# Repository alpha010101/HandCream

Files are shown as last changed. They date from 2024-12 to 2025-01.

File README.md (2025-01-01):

###
RP2040を使ったマイコン基板で、基本的にはRaspberry-pi pico互換。

24V系の機器を制御するのが目的で、そのために東芝のDMOS-SINKドライバTBD62064が載っている。本当ならカプラで分離するのが適当なのだろうが、こんなもんで問題なく動いてる

電源は24VをXHコネクタから入れる想定。それをTIのUA78M05で5V/0.5Aに落とし、それを更にMicrochipのMIC5504で3.3V/0.3Aに落としている。3.3VはMCU用、5VはLEDと冷却ファンの駆動用

SchematicsとPCB-LayoutはAutodesk-Eagle無償版を使用し、elecrowで製造することを想定したガーバーを作成している

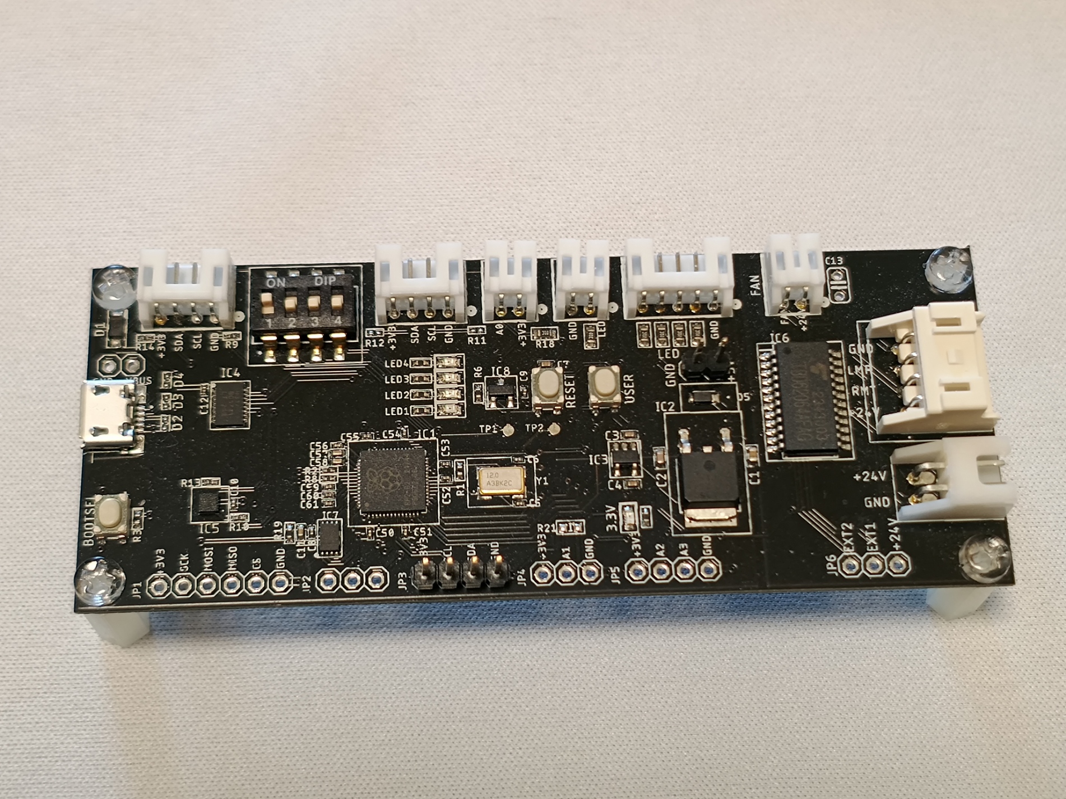
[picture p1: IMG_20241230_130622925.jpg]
HandCream


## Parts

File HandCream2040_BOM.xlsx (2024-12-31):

Part# | Device | Qty | Manufacturer | Package | Value | Description | Source | MOUSER_PART_NUMBER | MOUSER_PRICE-STOCK
C1 | CGA3E3X5R1H334K080AB | 1 | TDK | CAPC1608X90N | 0.33uF | Multilayer Ceramic Capacitor, 50V, 10%, X5R, 1608 (0603), Or equivalent | mouser or Elecrow | 810-CGA3E3X5R1H334KB | https://www.mouser.co.uk/ProductDetail/TDK/CGA3E3X5R1H334K080AB?qs=xLDY6iXSiQYI%252BjKItkDhww%3D%3D
C2 | C1608X5R1H104K080AA | 1 | TDK | CAPC1608X80N | 0.1uF | Multilayer Ceramic Capacitor, 50V, 10%, X5R, 1608 (0603), Or equivalent | mouser or Elecrow | 810-C1608X5R1H104K | https://www.mouser.co.uk/ProductDetail/TDK/C1608X5R1H104K080AA?qs=NRhsANhppD%2Fot2mSfg3j9A%3D%3D
C3,C4,C7 | GRM155R61E105KE11J | 3 | Murata Electronics | CAPC1005X55N | 1uF | Multilayer Ceramic Capacitor, 25V, 10%, X5R, 1005 (0402), Or equivalent | mouser or Elecrow | 81-GRM155R61E105KE1J | https://www.mouser.co.uk/ProductDetail/Murata-Electronics/GRM155R61E105KE11J?qs=QzBtWTOodeVRe4OtPvgZ4A%3D%3D
C5,C6 | GRM0335C1E150FA01D | 2 | Murata Electronics | CAPC0603X33N | 15pF | Multilayer Ceramic Capacitor, 25V, 1%, C0G, 0603 (0201), Or equivalent | mouser or Elecrow | 81-GRM0335C1E150FA1D | https://www.mouser.co.uk/ProductDetail/Murata-Electronics/GRM0335C1E150FA01D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
C8,C9,C10,C12,C50,C51,C52, C53,C54,C55,C56,C59,C60,C61 | GRM033R60J104KE19D | 14 | Murata Electronics | CAPC0603X33N | 0.1uF | Multilayer Ceramic Capacitor, 6.3V, 10%, X5R, 0603 (0201), Or equivalent | mouser or Elecrow | 81-GRM033R60J104KE19 | https://www.mouser.co.uk/ProductDetail/Murata-Electronics/GRM033R60J104KE19D?qs=GaSm9ipITa4x559m0GMeJg%3D%3D
C11,C57,C58 | GRM155R61A225KE01J | 3 | Murata Electronics | CAPC1005X55N | 2.2uF | Multilayer Ceramic Capacitor, 10V, 10%, X5R, 1005 (0402), Or equivalent | mouser or Elecrow | 81-GRM155R61A225K01J | https://www.mouser.co.uk/ProductDetail/Murata-Electronics/GRM155R61A225KE01J?qs=T3oQrply3y82IrfvEpRQug%3D%3D
C13 |  | 0 |  |  |  | No need to assemble
D1 | MBR120VLSFT1G | 1 | onsemi | SODFL3616X98N |  | Diode Schottky 20V, 1A, SOD-123FL | mouser or Elecrow | 863-MBR120VLSFT1G | https://www.mouser.co.uk/ProductDetail/onsemi/MBR120VLSFT1G?qs=3JMERSakebpX%252BkItPpFCkg%3D%3D
D2,D3,D4 | DF2S6.8FS,L3M | 0 | Toshiba | SODFL1006X45N |  | No need to assemble
D5 | VS-1EQH01HM3_H | 1 | Vishay | VS1EQH01HM3H |  | Rectifiers 100V 1A Fred Pt MicroSMP (DO-219AD) | mouser or Elecrow | 78-VS-1EQH01HM3/H | https://www.mouser.co.uk/ProductDetail/Vishay-Semiconductors/VS-1EQH01HM3-H?qs=BJlw7L4Cy78xxlCx4HTbcA%3D%3D
IC1 | SC0914(13) / RP2040 | 1 | RASPBERRY-PI | SC091413 |  | ARM Cortex-M0+ - Microcontroller IC 32-Bit Dual-Core 133MHz External Program Memory 56-QFN (7x7) | mouser or Elecrow | 358-SC091413 | https://www.mouser.co.uk/ProductDetail/Raspberry-Pi/SC091413?qs=T%252BzbugeAwjhr%252BUbBr3TJcw%3D%3D
IC2 | UA78M05CKVURG3 | 1 | Texas Instruments | TPS7A6533QKVURQ1 |  | Linear Voltage Regulators, 500mA, 5V-output, max25V, | mouser or Elecrow | 595-UA78M05CKVURG3 | https://www.mouser.co.uk/ProductDetail/Texas-Instruments/UA78M05CKVURG3?qs=0O%2FZFlpUpJXWzCHdAbvEiw%3D%3D
IC3 | MIC5504-3.3YM5-TR | 1 | Microchip | SOT95P280X145-5N |  | LDO Voltage Regulators, 300mA, 3.3V-output, max5.5V, SOT-23-5 | mouser or Elecrow | 998-MIC5504-3.3YM5TR | https://www.mouser.co.uk/ProductDetail/Microchip-Technology/MIC5504-3.3YM5-TR?qs=U6T8BxXiZAUmVQ5Zs217qQ%3D%3D
IC4 | LTC4317CDHC#PBF | 1 | Analog Devices | SON50P300X500X80-17N |  | Specialized Interface, I2C, SMBus, I2C Bus & SMBus Systems Applications, Servers, Telecom, 2.25 V | mouser or Elecrow | 584-LTC4317CDHC#PBF | https://www.mouser.com/Search/Refine.aspx?Keyword=584-LTC4317CDHC%23PBF
IC5 | MC3479 | 1 | MEMSIC | MC3479 |  | Accelerometers Small Digital 3-axis Accelerometer Sensor | mouser or Elecrow | 498-MC3479 | https://www.mouser.co.uk/ProductDetail/MEMSIC/MC3479?qs=OlC7AqGiEDmYmlaMvA9fTA%3D%3D
IC6 | TBD62064AFAG,EL | 1 | Toshiba | SOP100P800X190-24N |  | Gate Drivers DMOS Transistor Array 50V 1500mA | mouser or Elecrow | 757-TBD62064AFAGEHZ | https://www.mouser.co.uk/ProductDetail/Toshiba/TBD62064AFAGEL?qs=%252BEew9%252B0nqrBmaXxMy0ki7g%3D%3D
IC7 | W25Q16JVUXIQ_TR | 1 | Winbond | SON50P300X200X60-9N |  | NOR Flash spiFlash, 3V, 16M-bit, 4Kb Uniform Sector, DTR | mouser or Elecrow | 454-W25Q16JVUXIQTR | https://www.mouser.co.uk/ProductDetail/Winbond/W25Q16JVUXIQ-TR?qs=qSfuJ%252Bfl%2Fd7SDdIHLGOd1g%3D%3D
IC8 | MCP111T-315E_TT | 1 | Microchip | SOT96P237X112-3N |  | Voltage Supervisor 3.003 3.157 V, 3-Pin SOT-23B | mouser or Elecrow | 579-MCP111T-315E/TT | https://www.mouser.co.uk/ProductDetail/Microchip-Technology/MCP111T-315E-TT/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
J1 | S04B-XASS-1N-BN_LF__SN_ | 0 | JST | S04BXASS1NBNLFSN |  | No need to assemble
J2 | S2B-XH-A(LF)(SN) | 0 | JST | JST_S2B-XH-A(LF)(SN) |  | No need to assemble
J3,J4 | S4B-PH-K-S(LF)(SN) | 0 | JST | CONN_S4B-PH-K-S_JST |  | No need to assemble
J5,J6,J8 | S2B-PH-K-S(LF)(SN) | 0 | JST | CONN_S2B-PH-K-S_JST |  | No need to assemble
J7 | S5B-PH-K-S_(LF)(SN) | 0 | JST | CONN_S5B-PH-K-S_JST |  | No need to assemble
J9 | 10103594-0001LF | 1 | Amphenol ICC | AMPHENOL_10103594-0001LF |  | USB - micro B USB 2.0 Receptacle Connector 5 Position Surface Mount, Right Angle; Through Hole | mouser or Elecrow
LED1,LED2,LED3,LED4,LED5 | 150060VS75000 | 5 | Wurth Elektronik | LEDC1608X80N |  | Green LED, 2V/20mA, 1608 (0603) | mouser or Elecrow | 710-150060VS75000 | https://www.mouser.co.uk/ProductDetail/Wurth-Elektronik/150060VS75000?qs=LlUlMxKIyB1Q1Bi5mQ%2FKLw%3D%3D
R1,R3 | CRCW04021K00FKEDC | 2 | Vishay | RESC1005X35N | 1KΩ | Thick Film Resistor, 1005(0402), 1K, 1%, 0.063W(1/16W), Or equivalent | mouser or Elecrow | 71-CRCW04021K00FKEDC | https://www.mouser.co.uk/ProductDetail/Vishay-Dale/CRCW04021K00FKEDC?qs=E3Y5ESvWgWMj5mY%252BhDIyqg%3D%3D
R2,R8 | CRCW020127R0FNED | 2 | Vishay | RESC0603X28N | 27Ω | Thick Film Resistor, 0603(0201), 27, 1%, 0.05W(1/20W), Or equivalent | mouser or Elecrow | 71-CRCW020127R0FNED | https://www.mouser.co.uk/ProductDetail/Vishay-Dale/CRCW020127R0FNED?qs=3bSaU8eFeoG6a73XMZKF3w%3D%3D
R4,R7,R15,R16, R17,R18 | CRCW060310K0FKECC | 6 | Vishay | RESC1608X55N | 10KΩ | Thick Film Resistor, 1608(0603), 10K, 1%, 0.1W(1/10W), Or equivalent | mouser or Elecrow | 71-CRCW060310K0FKECC | https://www.mouser.co.uk/ProductDetail/Vishay-Dale/CRCW060310K0FKECC?qs=wd5RIQLrsJjYJGKL%252BLOtbQ%3D%3D
R21 | CRCW060310K0FKECC | 0 | Vishay | RESC1608X55N | 10KΩ | No need to assemble (pulldown)
R6,R19 | CRCW040210K0FKEDC | 2 | Vishay | RESC1005X35N | 10KΩ | Thick Film Resistor, 1005(0402), 10K, 1%, 0.063W(1/16W), Or equivalent | mouser or Elecrow | 71-CRCW040210K0FKEDC | https://www.mouser.co.uk/ProductDetail/Vishay-Dale/CRCW040210K0FKEDC?qs=E3Y5ESvWgWPiNLcGzwCGPg%3D%3D
R9,R10,R13,R14 | CRCW02014K70FNED | 4 | Vishay | RESC0603X28N | 4.7KΩ | Thick Film Resistor, 0603(0201), 4.7K, 1%, 0.05W(1/20W), Or equivalent | mouser or Elecrow | 71-CRCW02014K70FNED | https://www.mouser.co.uk/ProductDetail/Vishay-Dale/CRCW02014K70FNED?qs=9Aka%2FNDvCXDQ%2Fr1WGNjziQ%3D%3D
R11,R12 | CRCW02014K70FNED | 0 | Vishay | RESC0603X28N | 4.7KΩ | No need to assemble (I2C pullup)
R5,R22,R23,R24,R25 | CRCW0402620RFKED | 5 | Vishay | RESC1005X40N | 620Ω | Thick Film Resistor 1005(0402), 620, 1%, 0.063W(1/16W), Or equivalent | mouser or Elecrow | 71-CRCW0402-620-E3 | https://www.mouser.com/Search/Refine.aspx?Keyword=71-CRCW0402-620-E3
S1,S2,S3 | SKRPACE010 | 3 | ALPS Electric | SMT(4.2X3.2) |  | Tactile Switches 4.2x3.2x2.5mm 260gf | mouser or Elecrow | 688-SKRPACE010 | https://www.mouser.co.uk/ProductDetail/Alps-Alpine/SKRPACE010?qs=dHDuPHwQO79W8iY66hDbLQ%3D%3D
S4 | 219-4MST | 1 | CTS | 2194MST |  | DIP Switches / SIP Switches | mouser or Elecrow | 774-2194MST | https://www.mouser.co.uk/ProductDetail/CTS-Electronic-Components/219-4MST?qs=qNzHFtQhdJ8xGV2Z9mul9A%3D%3D
Y1 | ABM3BAIG-12.000MHZ-12-4-T | 1 | ABRACON | ABM3BAIG |  | 12 MHz +/-30ppm Crystal 12pF 70 Ohms 4-SMD, No Lead | mouser or Elecrow | 815-ABM3BAIG1212-4T | https://www.mouser.co.uk/ProductDetail/ABRACON/ABM3BAIG-12000MHz-12-4-T?qs=0lSvoLzn4L9fUl2r3xsu2A%3D%3D

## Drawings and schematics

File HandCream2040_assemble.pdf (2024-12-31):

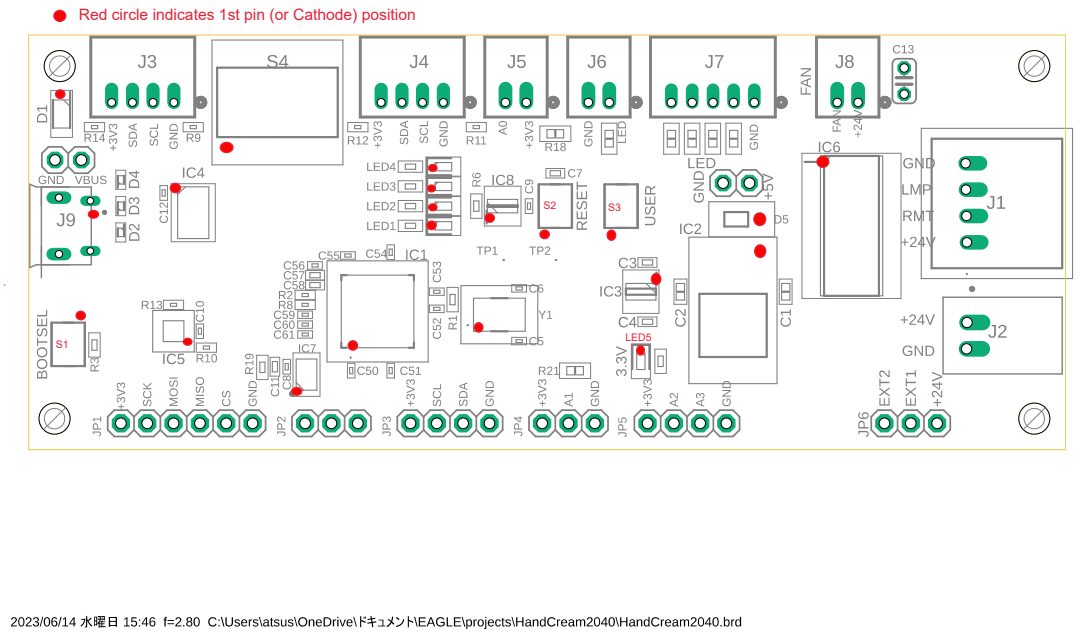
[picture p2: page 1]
LED5

Red circle indicates 1st pin (or Cathode) position

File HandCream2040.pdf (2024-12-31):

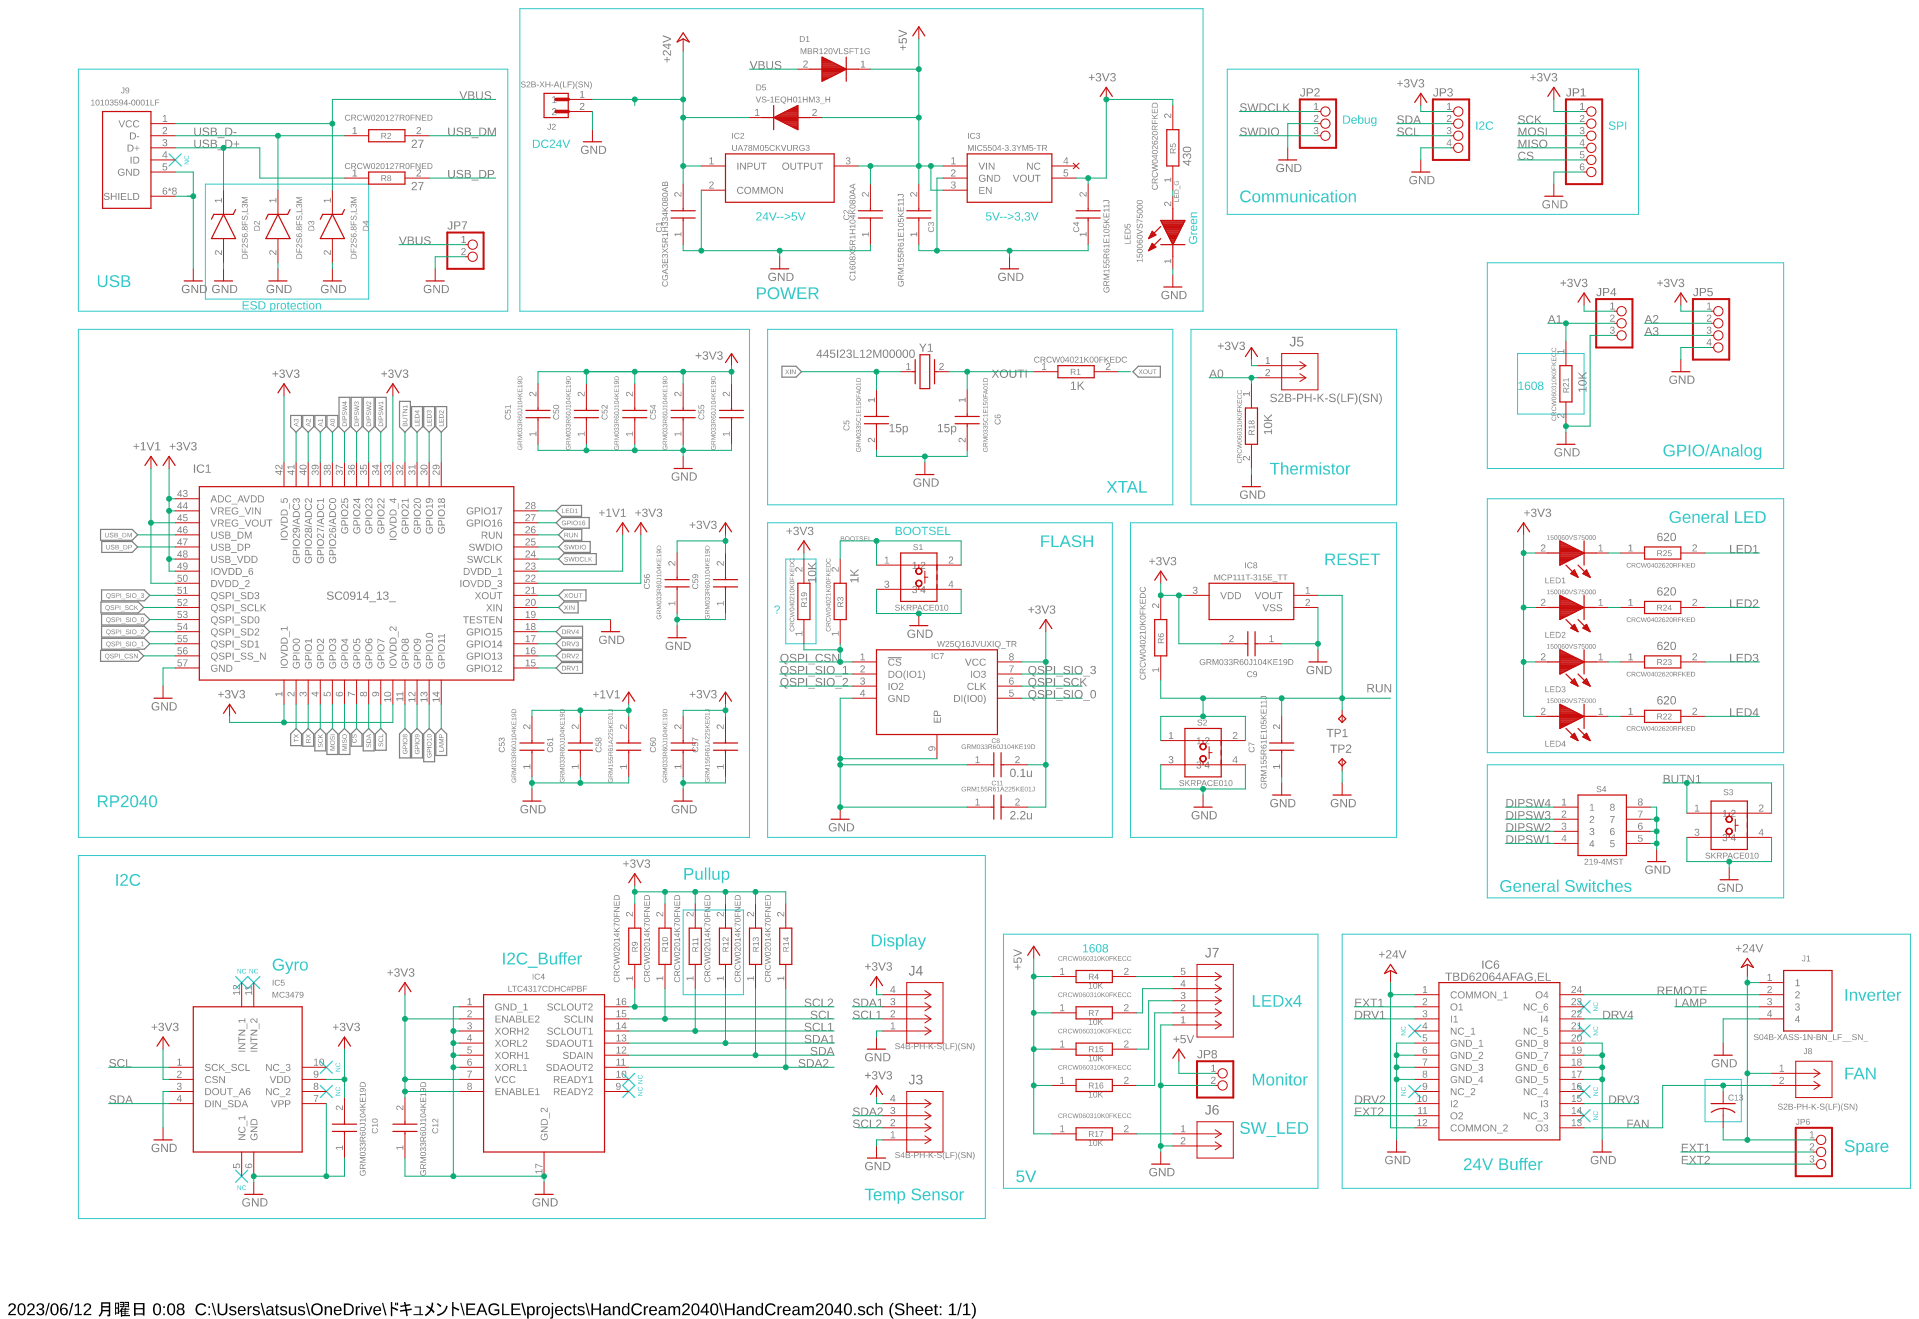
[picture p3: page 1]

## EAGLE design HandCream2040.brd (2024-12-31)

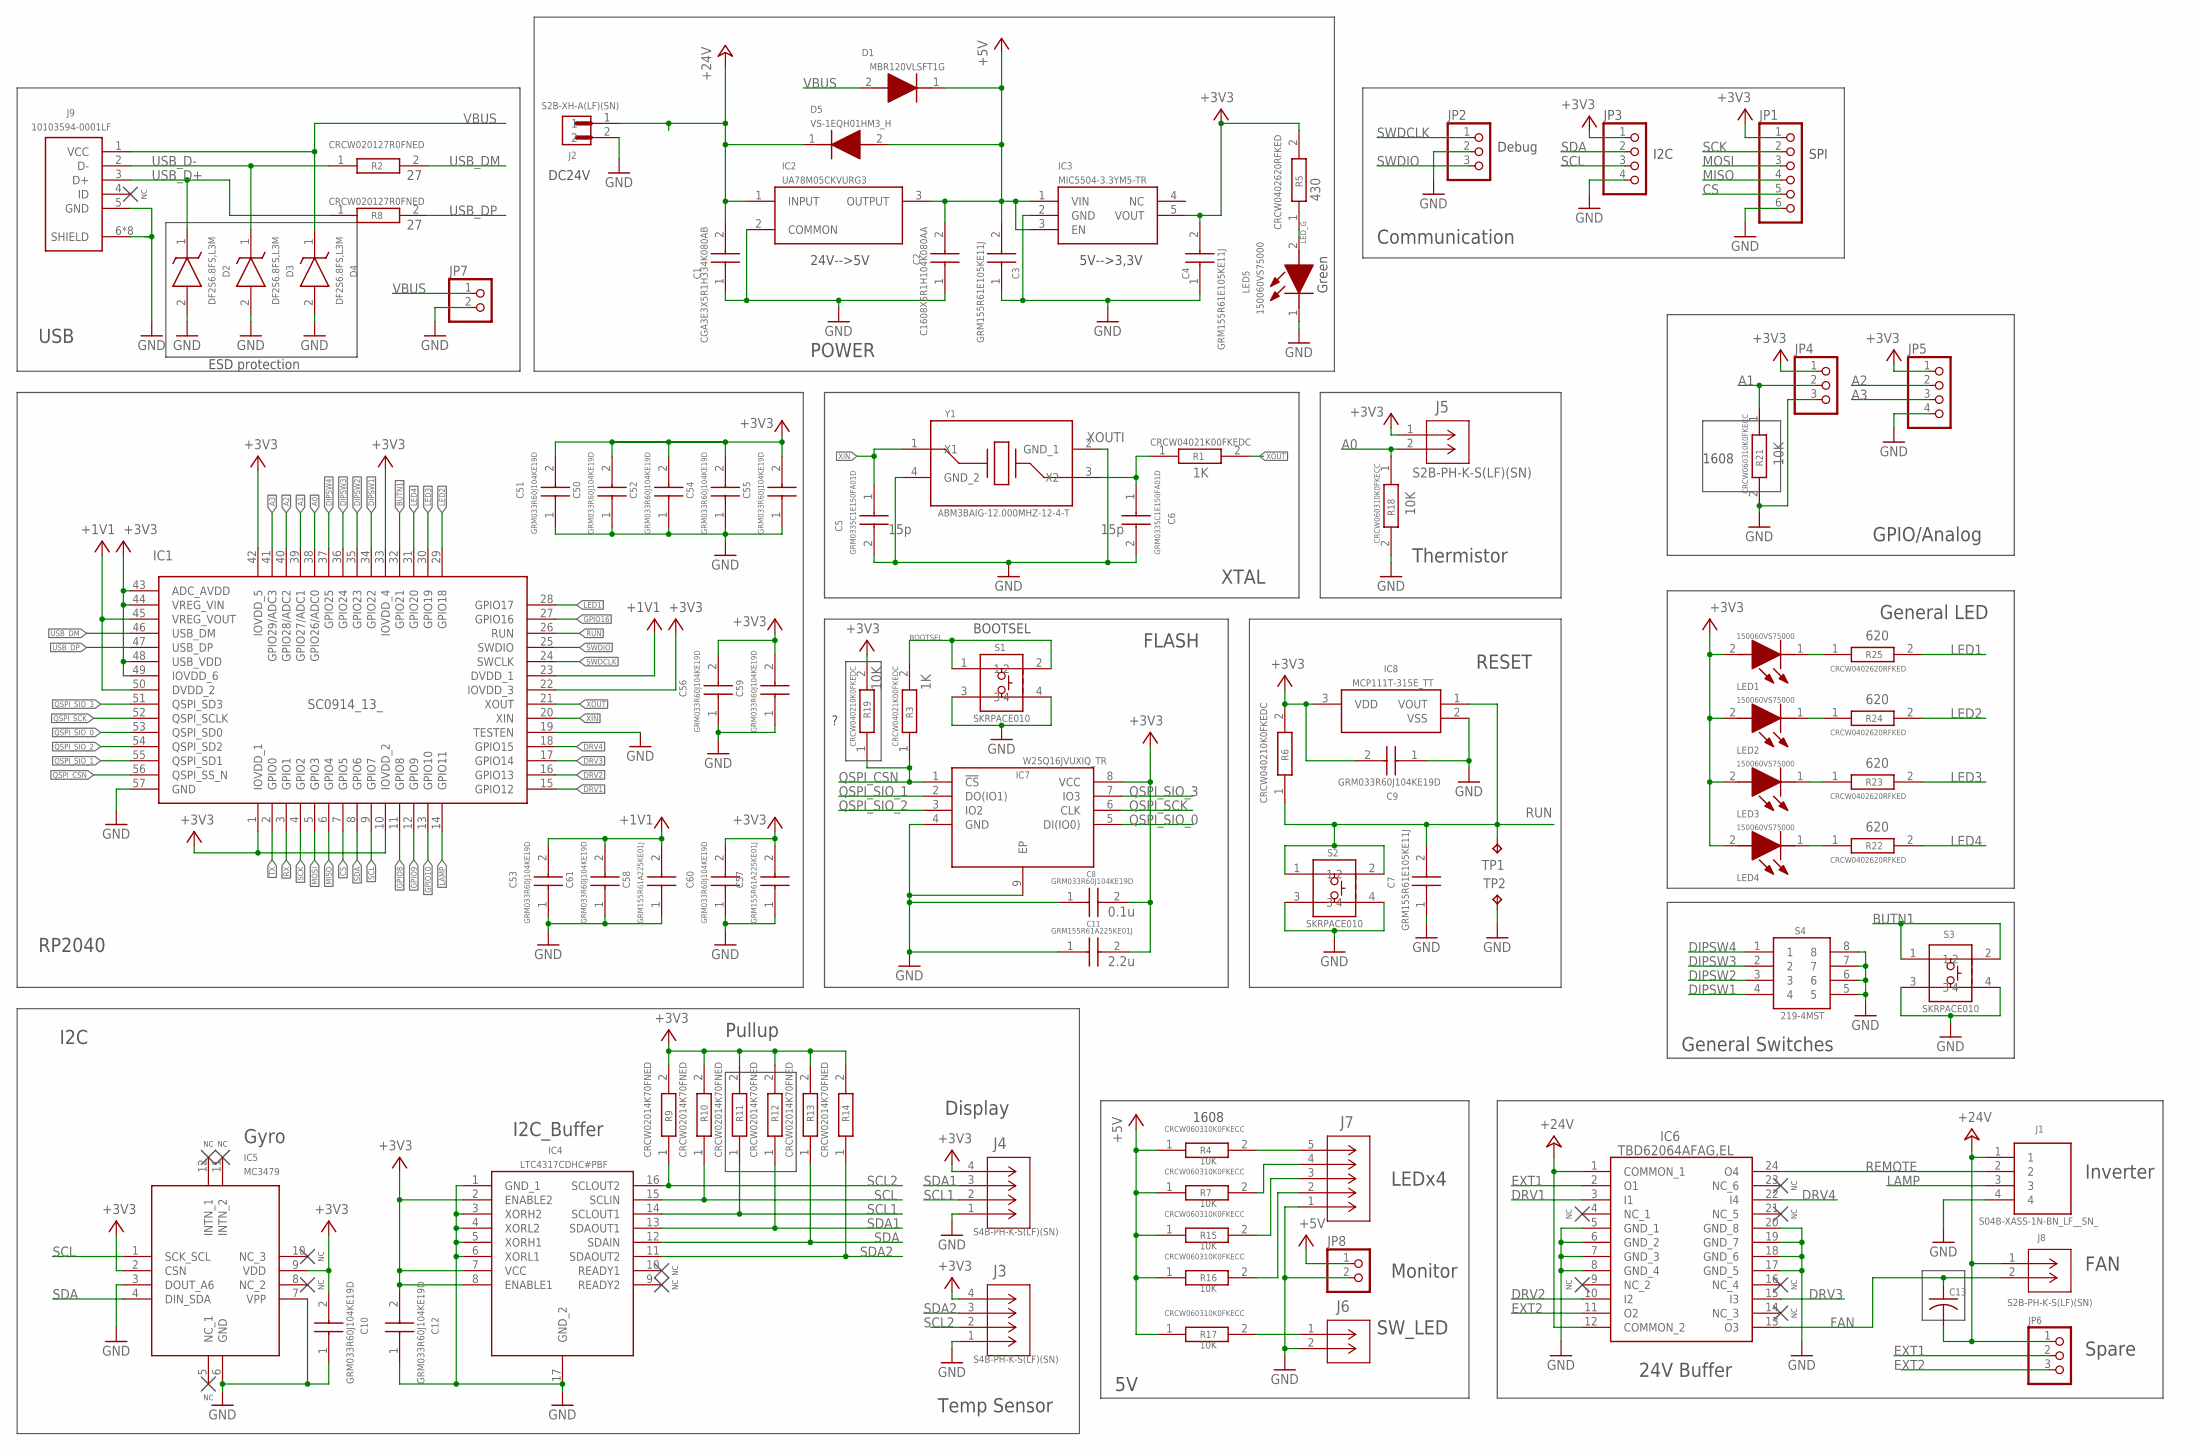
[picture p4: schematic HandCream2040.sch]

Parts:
C1: CGA3E3X5R1H334K080AB; CAPC1608X90N
C2: C1608X5R1H104K080AA; CAPC1608X80N
C3, C4, C7: GRM155R61E105KE11J; CAPC1005X55N
C5, C6: GRM0335C1E150FA01D; CAPC0603X33N
C8, C9, C10, C12, C50, C51, C52, C53, C54, C55, C56, C59, C60, C61: GRM033R60J104KE19D; CAPC0603X33N
C11, C57, C58: GRM155R61A225KE01J; CAPC1005X55N
C13: C-US025-024X044; C025-024X044
D1: MBR120VLSFT1G; SODFL3616X98N
D2, D3, D4: DF2S6.8FS,L3M; SODFL1006X45N
D5: VS-1EQH01HM3_H; VS1EQH01HM3H
IC1: SC0914_13_; SC091413
IC2: UA78M05CKVURG3; TPS7A6533QKVURQ1
IC3: MIC5504-3.3YM5-TR; SOT95P280X145-5N
IC4: LTC4317CDHC#PBF; SON50P300X500X80-17N
IC5: MC3479
IC6: TBD62064AFAG,EL; SOP100P800X190-24N
IC7: W25Q16JVUXIQ_TR; SON50P300X200X60-9N
IC8: MCP111T-315E_TT; SOT96P237X112-3N
J1: S04B-XASS-1N-BN_LF__SN_; S04BXASS1NBNLFSN
J2: S2B-XH-A(LF)(SN); JST_S2B-XH-A(LF)(SN)
J3, J4: S4B-PH-K-S(LF)(SN); CONN_S4B-PH-K-S_JST
J5, J6, J8: S2B-PH-K-S(LF)(SN); CONN_S2B-PH-K-S_JST
J7: S5B-PH-K-S_(LF)(SN); CONN_S5B-PH-K-S_JST
J9: 10103594-0001LF; AMPHENOL_10103594-0001LF
JP1: PINHD-1X6; 1X06
JP2, JP4, JP6: PINHD-1X3; 1X03
JP3, JP5: PINHD-1X4; 1X04
JP7, JP8: PINHD-1X2; 1X02
LED1, LED2, LED3, LED4, LED5: 150060VS75000; LEDC1608X80N
R1, R3: CRCW04021K00FKEDC; RESC1005X35N
R2, R8: CRCW020127R0FNED; RESC0603X28N
R4, R7, R15, R16, R17, R18, R21: CRCW060310K0FKECC; RESC1608X55N
R5, R22, R23, R24, R25: CRCW0402620RFKED; RESC1005X40N
R6, R19: CRCW040210K0FKEDC; RESC1005X35N
R9, R10, R11, R12, R13, R14: CRCW02014K70FNED; RESC0603X28N
S1, S2, S3: SKRPACE010; SMT(4.2X3.2)
S4: 219-4MST; 2194MST
TP1, TP2: TPB1,27; B1,27
Y1: ABM3BAIG-12.000MHZ-12-4-T; ABM3BAIG

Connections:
+1V1: C53.2, C58.2, C61.2, IC1.23 (DVDD_1), IC1.45 (VREG_VOUT), IC1.50 (DVDD_2)
+3V3: C4.2, C8.2, C9.2, C10.2, C11.2, C12.2, C50.2, C51.2, C52.2, C54.2, C55.2, C56.2, C57.2, C59.2, C60.2, IC1.1 (IOVDD_1), IC1.10 (IOVDD_2), IC1.22 (IOVDD_3), IC1.33 (IOVDD_4), IC1.42 (IOVDD_5), IC1.43 (ADC_AVDD), IC1.44 (VREG_VIN), IC1.48 (USB_VDD), IC1.49 (IOVDD_6), IC3.5 (VOUT), IC4.2 (ENABLE2), IC4.7 (VCC), IC4.8 (ENABLE1), IC5.2 (CSN), IC5.9 (VDD), IC7.8 (VCC), IC8.3 (VDD), J3.4, J4.4, J5.1, JP1.1, JP3.1, JP4.1, JP5.1, LED1.2 (A), LED2.2 (A), LED3.2 (A), LED4.2 (A), R5.2, R6.2, R9.2, R10.2, R11.2, R12.2, R13.2, R14.2, R19.2
+5V: C2.2, C3.2, D1.1 (K), D5.2 (A), IC2.3 (OUTPUT), IC3.1 (VIN), IC3.3 (EN), JP8.1, R4.1, R7.1, R15.1, R16.1, R17.1
+24V: C1.2, C13.2, D5.1 (K), IC2.1 (INPUT), IC6.1 (COMMON_1), IC6.12 (COMMON_2), J1.1, J2.1, J8.1, JP6.1
A0: IC1.38 (GPIO26/ADC0), J5.2, R18.1
A1: IC1.39 (GPIO27/ADC1), JP4.2, R21.1
A2: IC1.40 (GPIO28/ADC2), JP5.2
A3: IC1.41 (GPIO29/ADC3), JP5.3
BOOTSEL: R3.2, S1.1, S1.2
BUTN1: IC1.32 (GPIO21), S3.1, S3.2
CS: IC1.7 (GPIO5), JP1.5
DIPSW1: IC1.34 (GPIO22), S4.4
DIPSW2: IC1.35 (GPIO23), S4.3
DIPSW3: IC1.36 (GPIO24), S4.2
DIPSW4: IC1.37 (GPIO25), S4.1
DRV1: IC1.15 (GPIO12), IC6.3 (I1)
DRV2: IC1.16 (GPIO13), IC6.10 (I2)
DRV3: IC1.17 (GPIO14), IC6.15 (I3)
DRV4: IC1.18 (GPIO15), IC6.22 (I4)
EXT1: IC6.2 (O1), JP6.2
EXT2: IC6.11 (O2), JP6.3
FAN: C13.1, IC6.13 (O3), J8.2
GND: C1.1, C2.1, C3.1, C4.1, C5.2, C6.2, C7.1, C8.1, C9.1, C10.1, C11.1, C12.1, C50.1, C51.1, C52.1, C53.1, C54.1, C55.1, C56.1, C57.1, C58.1, C59.1, C60.1, C61.1, D2.2 (A), D3.2 (A), D4.2 (A), IC1.19 (TESTEN), IC1.57 (GND), IC2.2 (COMMON), IC3.2 (GND), IC4.1 (GND_1), IC4.3 (XORH2), IC4.4 (XORL2), IC4.5 (XORH1), IC4.6 (XORL1), IC4.17 (GND_2), IC5.3 (DOUT_A6), IC5.6 (GND), IC5.7 (VPP), IC6.5 (GND_1), IC6.6 (GND_2), IC6.7 (GND_3), IC6.8 (GND_4), IC6.17 (GND_5), IC6.18 (GND_6), IC6.19 (GND_7), IC6.20 (GND_8), IC7.4 (GND), IC7.9 (EP), IC8.2 (VSS), J1.4, J2.2, J3.1, J4.1, J6.2, J7.1, J9.5 (GND), J9.6 (SHIELD), J9.7 (SHIELD), J9.8 (SHIELD), J9.9 (SHIELD), J9.10 (SHIELD), J9.11 (SHIELD), J9.S1 (SHIELD), J9.S2 (SHIELD), JP1.6, JP2.2, JP3.4, JP4.3, JP5.4, JP7.2, JP8.2, LED5.1 (K), R18.2, R21.2, S1.3, S1.4, S2.3, S2.4, S3.3, S3.4, S4.5, S4.6, S4.7, S4.8, TP2.TP, Y1.2 (GND_1), Y1.4 (GND_2)
GPIO8: IC1.11 (GPIO8)
GPIO9: IC1.12 (GPIO9)
GPIO10: IC1.13 (GPIO10)
GPIO16: IC1.27 (GPIO16)
LAMP: IC1.14 (GPIO11), J1.3
LED1: IC1.28 (GPIO17), R25.2
LED2: IC1.29 (GPIO18), R24.2
LED3: IC1.30 (GPIO19), R23.2
LED4: IC1.31 (GPIO20), R22.2
LED_G: LED5.2 (A), R5.1
MISO: IC1.6 (GPIO4), JP1.4
MOSI: IC1.5 (GPIO3), JP1.3
unnamed: J7.5, R4.2
unnamed: J7.4, R7.2
unnamed: J7.3, R15.2
unnamed: J7.2, R16.2
unnamed: J6.1, R17.2
unnamed: LED1.1 (K), R25.1
unnamed: LED2.1 (K), R24.1
unnamed: LED3.1 (K), R23.1
unnamed: LED4.1 (K), R22.1
QSPI_CSN: IC1.56 (QSPI_SS_N), IC7.1 (!CS), R3.1, R19.1
QSPI_SCK: IC1.52 (QSPI_SCLK), IC7.6 (CLK)
QSPI_SIO_0: IC1.53 (QSPI_SD0), IC7.5 (DI(IO0))
QSPI_SIO_1: IC1.55 (QSPI_SD1), IC7.2 (DO(IO1))
QSPI_SIO_2: IC1.54 (QSPI_SD2), IC7.3 (IO2)
QSPI_SIO_3: IC1.51 (QSPI_SD3), IC7.7 (IO3)
REMOTE: IC6.24 (O4), J1.2
RUN: C7.2, IC1.26 (RUN), IC8.1 (VOUT), R6.1, S2.1, S2.2, TP1.TP
RX: IC1.3 (GPIO1)
SCK: IC1.4 (GPIO2), JP1.2
SCL: IC1.9 (GPIO7), IC4.15 (SCLIN), IC5.1 (SCK_SCL), JP3.3, R10.1
SCL1: IC4.14 (SCLOUT1), J4.2, R11.1
SCL2: IC4.16 (SCLOUT2), J3.2, R9.1
SDA: IC1.8 (GPIO6), IC4.12 (SDAIN), IC5.4 (DIN_SDA), JP3.2, R13.1
SDA1: IC4.13 (SDAOUT1), J4.3, R12.1
SDA2: IC4.11 (SDAOUT2), J3.3, R14.1
SWDCLK: IC1.24 (SWCLK), JP2.1
SWDIO: IC1.25 (SWDIO), JP2.3
TX: IC1.2 (GPIO0)
USB_D+: D2.1 (K), J9.3 (D+), R8.1
USB_D-: D3.1 (K), J9.2 (D-), R2.1
USB_DM: IC1.46 (USB_DM), R2.2
USB_DP: IC1.47 (USB_DP), R8.2
VBUS: D1.2 (A), D4.1 (K), J9.1 (VCC), JP7.1
XIN: C5.1, IC1.20 (XIN), Y1.1 (X1)
XOUT: IC1.21 (XOUT), R1.2
XOUTI: C6.1, R1.1, Y1.3 (X2)

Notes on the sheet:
USB
POWER
RP2040
FLASH
XTAL
RESET
BOOTSEL
I2C
Gyro
Display
Temp Sensor
LEDx4
SW_LED
24V Buffer
Monitor
Inverter
FAN
Spare
Thermistor
General Switches
Green
24V-->5V
5V-->3,3V
DC24V
Debug
I2C_Buffer
Pullup
General LED
SPI
Communication
GPIO/Analog
ESD protection
1608

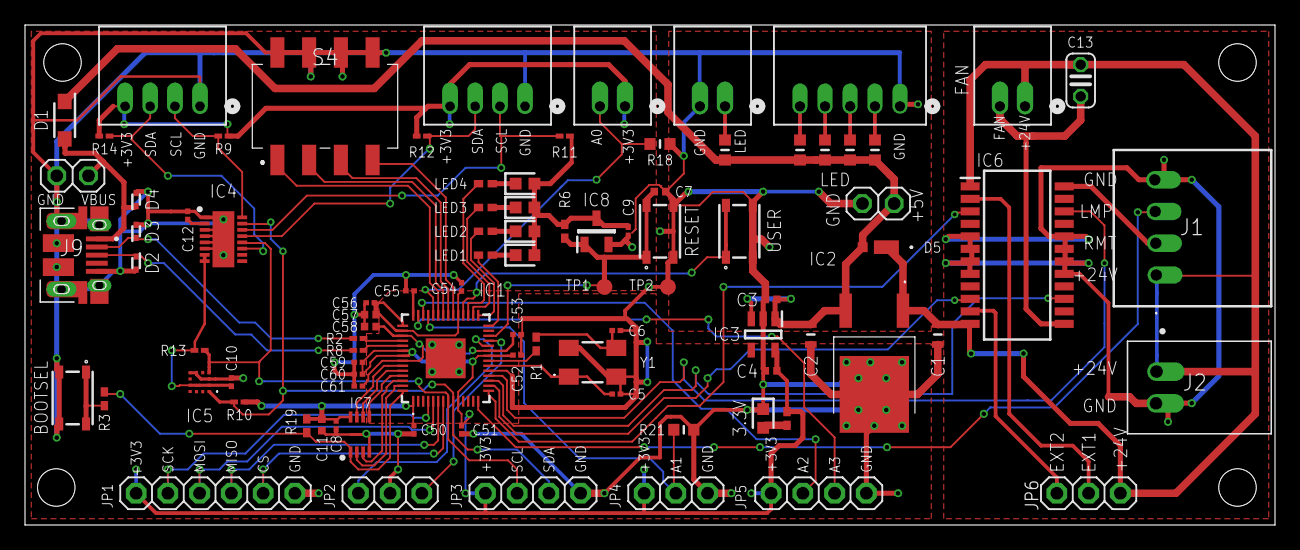
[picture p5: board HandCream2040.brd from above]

Board: 2 copper layers, 100.0 x 40.0 mm, 91 parts (0 on the bottom side), 65 nets.

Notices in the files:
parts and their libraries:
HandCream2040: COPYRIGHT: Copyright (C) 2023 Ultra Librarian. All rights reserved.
